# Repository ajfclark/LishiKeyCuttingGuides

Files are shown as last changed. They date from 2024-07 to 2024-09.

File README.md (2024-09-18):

# LishiKeyCuttingGuides - Generation toolkit

This is a version of Deviant and Tony's [original
work](https://github.com/deviantollam/LishiKeyCuttingGuides) that is focussed
on:

 - Providing a toolkit for generating guides for other formats, including a
   mirror-mode option to support warding that prefers cutting a key with the
   bow on the right.
 - More forgiving geometry for cheaper 3D printers
 - An optional "wide" mode including a guide to help locate the shoulder for
   each pin

The consequence of this flexibility is the loss of the included Schlage
warding in the original project, which does reduce some of the alignment
effect.

The original repository's README is included [below](#the-original-readme),
for more context and attribution, and I've kept their original reference STLs
for Schlage in the [references](references/) subfolder, along with the Schlage
marker sleeve for pin positions.

## Images

### Model

These two images are the default and wide-mode generated versions (for 6-pin
Schlage, as above):

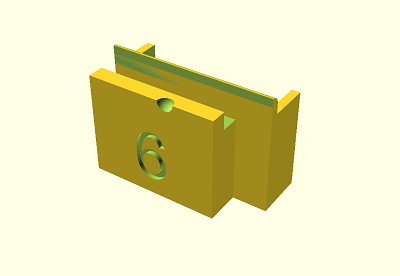
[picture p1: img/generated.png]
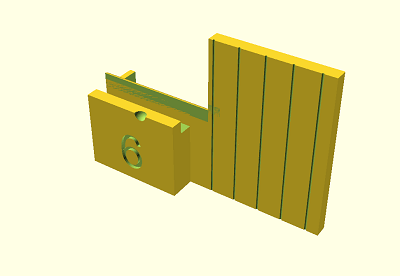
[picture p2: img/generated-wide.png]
 

And this is an example of the original reference STLs:

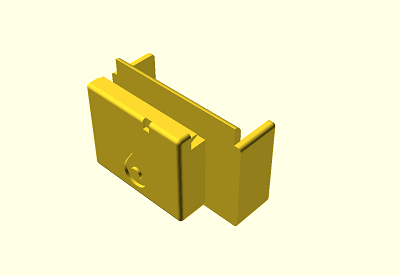
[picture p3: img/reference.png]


### Prints

Here are examples of the wide mode set of guides for Lockwood. A learning here
is for depths 7-9 it's better to first do a 4 or 5 depth, then do the second
one as the key cannot fit between the raised punch and the guide otherwise.
Another learning was that the process bent the key slightly, and I suspect
that additional support under the key (even a piece of paper) would have
avoided this. The Lockwood profile doesn't have the blade all against one
side, so the punching process can't help bend it.

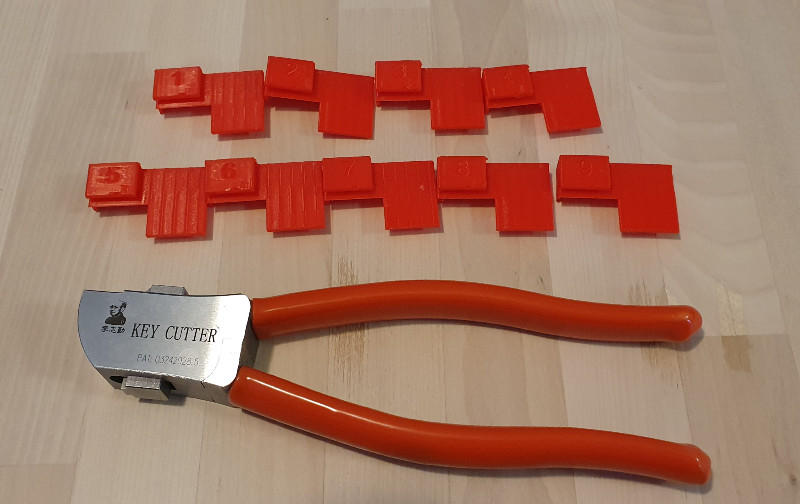
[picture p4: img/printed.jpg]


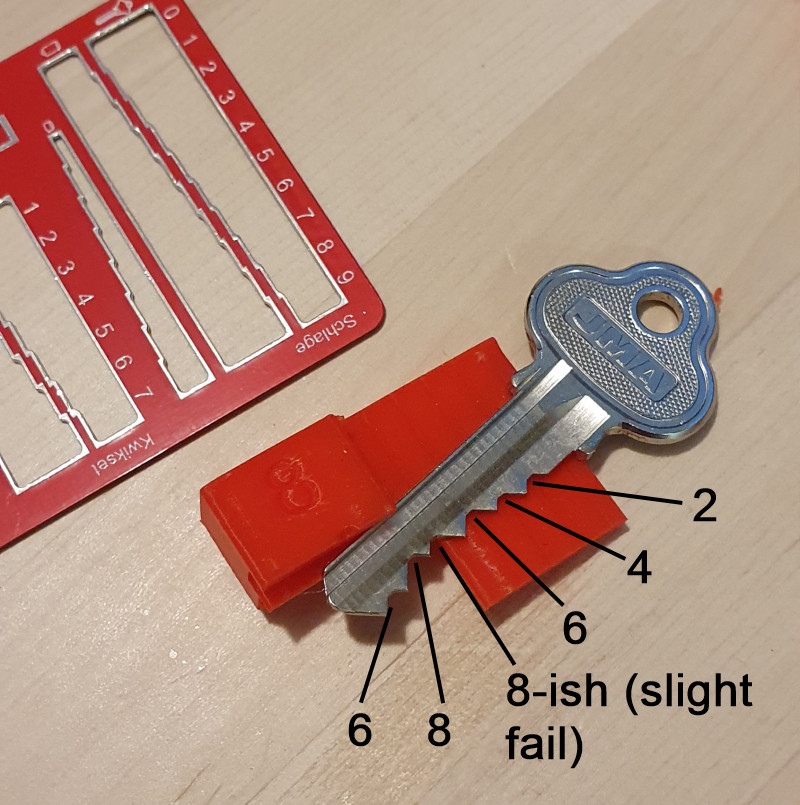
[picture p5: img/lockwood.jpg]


## Generating guides

### Windows

The script `generate.bat` is used to create the guides, into the
[generated](generated/) subfolder. I've put a few of them in there for
reference.

As per the variable at the top of the file, the script expects OpenSCAD to be
installed in `C:\Program Files\OpenSCAD\openscad.exe`, update that as you
need.

Run it with arguments `generate.bat Schlage left 8.509 0.381 5.86 10 0` where:

 - `Schlage` is the key name/label for output files etc.
 - `left` has the key coming in from the left, when mounted to the pliers.
 - `8.509` is the zero cut height, in mm.
 - `0.381` is the size of each step in depth, in mm.
 - `5.86` is the distance from pin 1 to the shoulder, in mm.
 - `10` is the total number of possible depths, including the zero cut.
 - `0` is the numeric code for the zero cut.

The above numbers will generate 9 guides for Schlage, which I've done into the
[generated](generated/) folder. The zero cut is not generated because it's
very hard to correctly cut.

If you append the arguments `wide 3.96 6` at the end of the parameters, it
will add enough indents to help you align cuts for 6 pins without using the
[Schlage Marker Sleeve.stl](references/Schlage%20Key%20Marker%20Sleeve.stl)
(the spacing will be 3.96mm, for Schlage). This does compromise how compact
the guides are, but may work for your use case. I've included the output of
`generate.bat Schlage left 8.509 0.381 5.86 10 0 wide 3.96 6` into the same
[generated](generated/) folder.

### Linux

As above, but with ./generate.sh ...

## TODOs

 - [ ] Finger hook - restore?
 - [ ] Horizontal cut to help keep key aligned with pin 6 etc?
 - [ ] Set file name to match depth code, instead of zero-based depth index.
 - [ ] "Known" configs for bump keys.
 - [ ] Variable height holder for different thickness keys.

## Known good configurations

 - Schlage: `Schlage left 8.509 0.381 5.86 10 0` + `wide 3.96 6`
 - Kwikset: `Kwikset left 8.8 0.59 6.27 8 1` + `wide 3.81 6`
 - Lockwood: `Lockwood right 8.509 0.381 5.86 10 0` + `wide 3.96 6`

## The original README

3D printable files for the ersatz Pak-A-Punch developed by Deviant and Tony of 3D Locksport

To those who do not know of the history of the Pak-A-Punch, by the way... that tool was the brainchild of Ricky Lee King (and his collaborator Rob Robinson, both from Richmond, VA) who was the main individual behind A-1 Security Manufacturing.  With multiple patents to his name, his contribution to the locksmithing world was immense and his passing leaves a significant void in our industry.  When Mr. King passed away, the A-1 company appeared to die along with him.  Thus, the Pak-A-Punch is no longer available.

A number of improvised and ersatz hacks to replace it have been kludged together in the past, but here at Red Team Tools we wanted to offer something a bit more robust and functional than what's been put out there in the past.  None of us could likely ever replace the Pak-A-Punch, but this small set of guides that attach to the Lishi Key Cutter helps us come close, perhaps!

By attaching these printed guide blocks to the front end of a pair of Lishi Key Nipper Pliers (also sold here on Red Team Tools) you can make calibrated cuts to your key blade at the proper manufacturer bitting depths for Schlage systems.  (It is nearly impossible to make an accurate 0-depth cut on a key blade using Lishi Nippers so we recommend that users start with 0-bitted, pre-scored key blanks during this process.  Such keys will also help to ensure that your cuts are made at the proper position laterally along the blade.)

Additional description and demonstration of the use of these Key Cutter Guides can be seen in this video here...

 https://www.youtube.com/watch?v=MVNUbwL26H4

Many thanks to Tony Virelli for his help with bringing this design to life and getting the first prints made while we tested and refined this product

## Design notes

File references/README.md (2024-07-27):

These are snapshot of the STL files from Deviant and Tony's [original
work](https://github.com/deviantollam/LishiKeyCuttingGuides), as reference
geometry for Schlage.

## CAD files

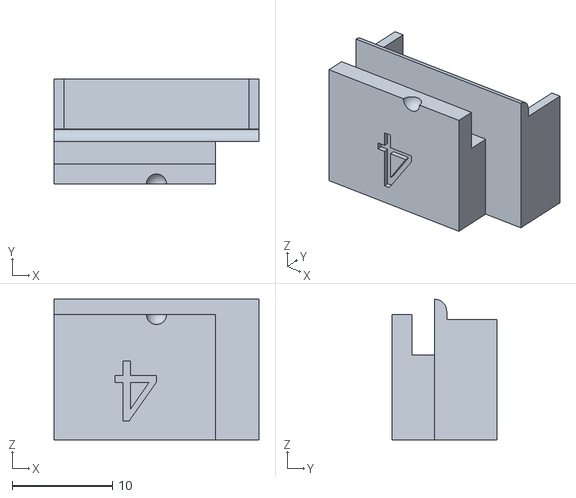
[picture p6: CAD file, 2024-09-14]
generated/Schlage Cutter Guide - 4.stl
20.4 x 10.4 x 14.0

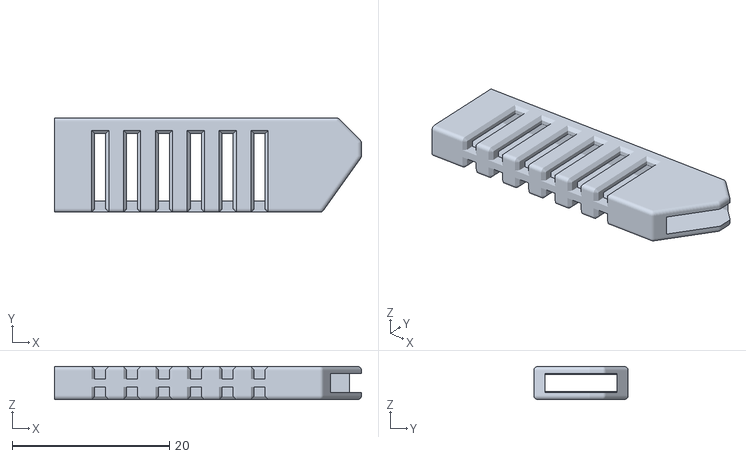
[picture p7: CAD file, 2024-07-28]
references/Schlage Key Marker Sleeve.stl
39.0 x 12.0 x 4.20

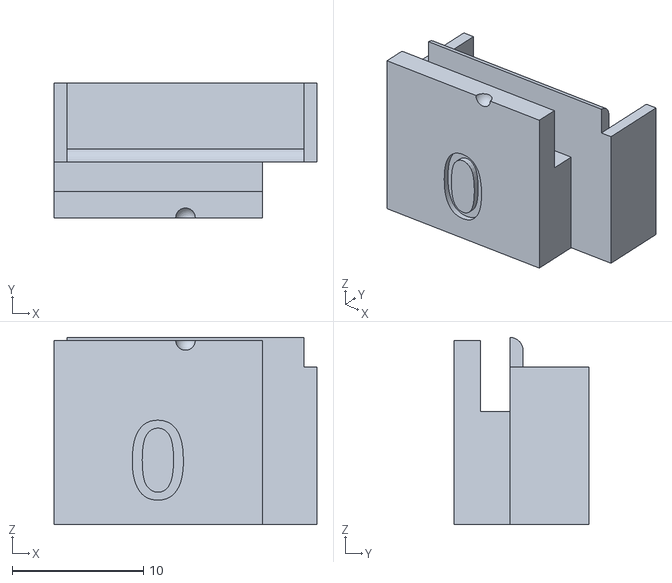
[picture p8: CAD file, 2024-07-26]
generate/Schlage Cutter Guide - 0.stl
20.0 x 10.2 x 14.2

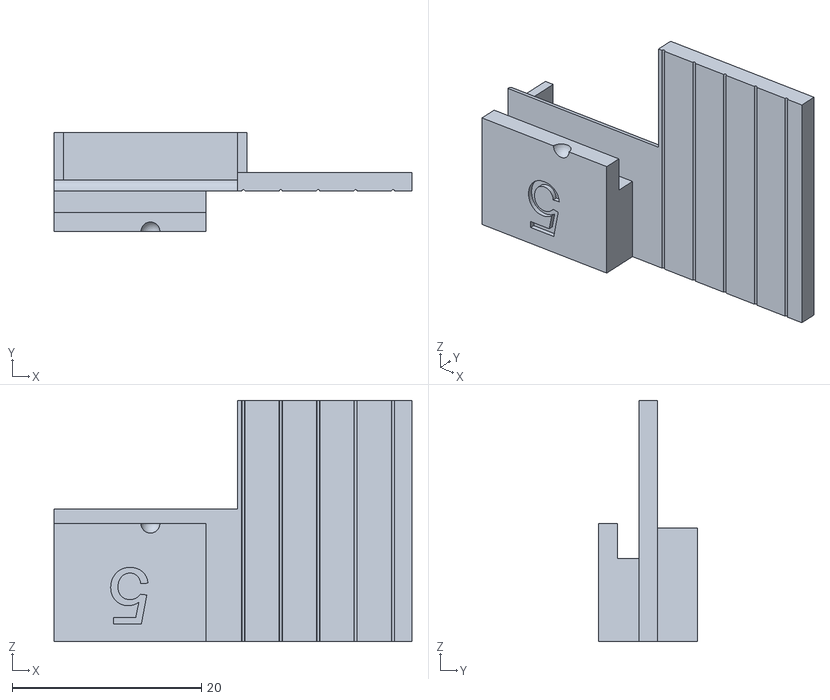
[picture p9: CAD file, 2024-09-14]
generated/Schlage Wide Cutter Guide - 5.stl
37.9 x 10.4 x 25.5

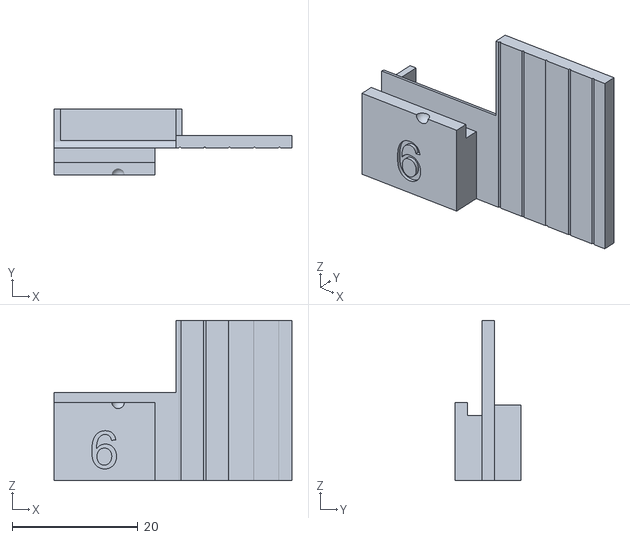
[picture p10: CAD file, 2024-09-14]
generated/Schlage Wide Cutter Guide - 9.stl
37.9 x 10.4 x 25.5

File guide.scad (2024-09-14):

/*
Command line config settings, for the key type, overridden by generate.bat

The below default values are for Schlage.
*/
tab_side = "left";
zero_cut_root_depth = 8.509;
depth_step = 0.381;
pin_1_from_shoulder = 5.86;
total_depths = 10;
depth_index = 9;
zero_cut_number = 0;

/*
Additional command line settings if generating wide version.
*/
wide_mode = false;
pin_spacing = 3.96;
total_pins = 6;

// Lishi pliers dimensions.
lishi_socket_width = 18 + 0.3;  // 0.3 from my printer, you may need to tweak.
lishi_socket_height = 5;
lishi_socket_length = 10;
lishi_lip_length = 2;
lishi_lip_thickness = 1.2;
lishi_socket_punch_length = 13.415;  // Tip of punch to end of lishi.

// Guide config.
$fn = 30;
walls = 1;
key_slot_width = 2.25;
cover_overlap = 2.14;
aligner_inset = 1;

// Derived dimensions
guide_back_width = lishi_socket_width + walls*2;
guide_back_length = lishi_socket_length + walls*2;
guide_back_height = lishi_socket_height + lishi_lip_thickness;

guide_front_length = lishi_socket_punch_length + walls*2 - zero_cut_root_depth + ((total_depths-1) * depth_step) + cover_overlap;
guide_front_height = key_slot_width + walls*2;
guide_front_width = guide_back_width / 2 + pin_1_from_shoulder;

lip_width = guide_back_width;

guide_back_wing_width = guide_front_width+(pin_spacing*(total_pins-1))+walls*3 - guide_back_width;
guide_back_wing_length = guide_back_length + zero_cut_root_depth + 5;
shoulder_line = aligner_inset / 3;

mirror_tab = tab_side == "right";

mirror([mirror_tab ? 1 : 0, 0, 0]) difference() {
    union() {
        // Guide back - clips to Lishi pliers.
        translate([-walls, 0, -walls*2]) difference() {
            union() {
                cube([guide_back_width, guide_back_height, guide_back_length]);
                if (wide_mode) {
                    translate([guide_back_width-walls, 0, 0]) cube([guide_back_wing_width, walls*2, guide_back_wing_length]);
                }
            }

            translate([walls,lishi_lip_thickness,walls*2]) cube([lishi_socket_width, guide_back_height, guide_back_length]);
        }

        // Lip.
        translate([-walls, 0, lishi_socket_length]) {
            cube([lip_width, lishi_lip_thickness, lishi_lip_length-lishi_lip_thickness]);
            difference() {
                translate([0, 0, lishi_lip_length-lishi_lip_thickness]) {
                    rotate([0, 90, 0]) cylinder(h=lip_width, r=lishi_lip_thickness);
                }
                mirror([0, 1, 0]) translate([-1, 0, -lishi_lip_thickness]) cube([lip_width+2, lishi_lip_thickness+1, lishi_lip_length+lishi_lip_thickness]);
            }
        }
    }
    // Shoulder guides.
    translate([-walls, 0, -walls*2]) if (wide_mode) {
        for (i = [1 : total_pins-1]){
            translate([guide_front_width+(pin_spacing * i), 0, -walls]) {
                cylinder(d=shoulder_line, h=guide_back_wing_length+walls*2);
            }
        }
    }
}

// Cover with alignment slot, depth bar and number.
mirror([mirror_tab ? 1 : 0, 0, 0]) translate([-walls, 0, -walls*2]) difference() {
    mirror([0, 1, 0]) cube([guide_front_width, guide_front_height, guide_front_length]);

    // Alignment.
    translate([guide_back_width/2, -guide_front_height, guide_front_length]) sphere(r=aligner_inset);
    
    // Depth bar.
    bar_push = lishi_socket_punch_length - zero_cut_root_depth + (depth_index * depth_step) + walls*2;
    translate([-5, -key_slot_width, bar_push]) cube([lishi_socket_width*2, key_slot_width+1, 30]);

    // Number.
    translate([guide_front_width/2, -guide_front_height+0.5, 2]) rotate([-90, 0, 180]) {
        mirror([mirror_tab ? 1 : 0, 0, 0]) linear_extrude(1) text(str(depth_index+zero_cut_number), size=6, font="Arial", halign="center", valign="top");
    }
}

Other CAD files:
references/Schlage Cutter Guide - 3.stl
generated/Schlage Wide Cutter Guide - 1.stl
references/Schlage Cutter Guide - 8.stl
references/Schlage Cutter Guide - 9.stl
generated/Lockwood Wide Cutter Guide - 3.stl
references/Schlage Cutter Guide - 6.stl
generated/Schlage Cutter Guide - 3.stl
references/Schlage Cutter Guide - 1.stl
generated/Schlage Cutter Guide - 5.stl
references/Schlage Cutter Guide - 5.stl
generated/Lockwood Cutter Guide - 1.stl
references/Schlage Cutter Guide - 2.stl
generated/Lockwood Wide Cutter Guide - 5.stl
generate/Schlage Cutter Guide - 1.stl
generate/Schlage Cutter Guide - 2.stl
generate/Schlage Cutter Guide - 3.stl
generate/Schlage Cutter Guide - 4.stl
generate/Schlage Cutter Guide - 5.stl
generate/Schlage Cutter Guide - 6.stl
generate/Schlage Cutter Guide - 7.stl
generate/Schlage Cutter Guide - 8.stl
generate/Schlage Cutter Guide - 9.stl
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

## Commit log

2024-07-26 First pass at generation of guides
    [Schlage Cutter Guide - 0.stl, Schlage Cutter Guide - 1.stl, Schlage Cutter Guide - 2.stl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]
2024-07-26 The idea for the pin position guides
    [guide.scad]
2024-07-26 Started the merge
    [Schlage Cutter Guide - 0.stl, Schlage Cutter Guide - 1.stl, Schlage Cutter Guide - 2.stl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]
2024-07-26 Moved the reference STLs to a dedicated location
    [Schlage Cutter Guide - 1.stl, Schlage Cutter Guide - 2.stl, Schlage Cutter Guide - 3.stl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]
2024-07-27 Really need to standardise naming
    [guide.scad]
2024-07-27 Made wide mode conditional
    [guide.scad]
2024-07-27 Added wide-mode generation and samples.
    Also a gentle reminder why I should have done this on linux...
    [Schlage Cutter Guide - 0.stl, Schlage Cutter Guide - 1.stl, Schlage Cutter Guide - 2.stl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]
2024-07-28 Moved reference file, updated README
    [Schlage Key Marker Sleeve.stl]
2024-07-28 Removed zero cut
    [Schlage Cutter Guide - 0.stl, Schlage Wide Cutter Guide - 0.stl]
2024-08-02 Variable pass through
    [guide.scad]
2024-08-04 Enlarged shoulder marks for when the shoulder is only on the bitting side
    [guide.scad]
2024-08-04 Fixed major geometry error
    I had assumed the key sat on the protrusion, but that was to hold the bitting.
    [Schlage Cutter Guide - 1.stl, Schlage Cutter Guide - 2.stl, Schlage Cutter Guide - 3.stl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]
2024-08-08 Added padding for my printer to make the width snug
    [guide.scad]
2024-08-08 Corrected lip geometry slightly
    Shorter, and thicker
    [guide.scad]
2024-08-11 Mirror mode
    [guide.scad]
2024-08-11 Updated models
    [Schlage Cutter Guide - 1.stl, Schlage Cutter Guide - 2.stl, Schlage Cutter Guide - 3.stl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]
2024-09-01 Trialling Lockwood exports
    [Lockwood Cutter Guide - 1.stl, Lockwood Cutter Guide - 2.stl, Lockwood Cutter Guide - 3.stl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]
2024-09-14 Printer calibration tweaks
    [Lockwood Cutter Guide - 1.stl, Lockwood Cutter Guide - 2.stl, Lockwood Cutter Guide - 3.stl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]
